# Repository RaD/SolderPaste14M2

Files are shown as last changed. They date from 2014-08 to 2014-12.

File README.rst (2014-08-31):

This is a clone of `Solder Paste Controller`__ project from Dead Bug Prototypes.

__ https://www.tindie.com/products/Dead_Bug_Prototypes/solder-paste-controller/

The main differences are:

- Usage ATtiny13 as a MCU.
- Firmware is written with assembler language.

Flashing:

    sudo \
    avrdude -p attiny13 \
            -c usbasp \
            -P usb
            -U lfuse:w:0x6A:m -U hfuse:w:0xFF:m
            -U flash:w:solderpaste.hex

Fuse online editor: http://www.engbedded.com/fusecalc/

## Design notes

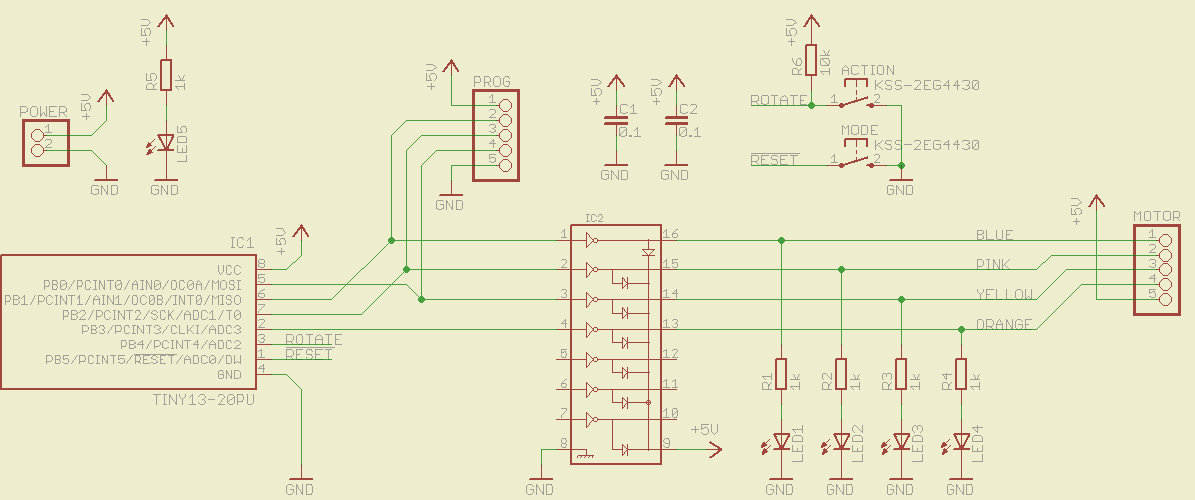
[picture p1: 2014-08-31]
pcb/schematic.png

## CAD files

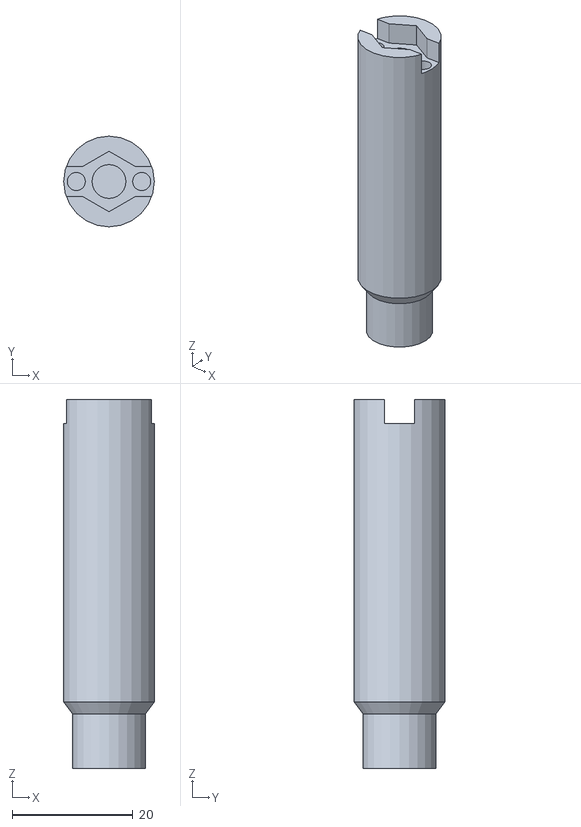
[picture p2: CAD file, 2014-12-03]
reprap/plunger.stl
15.0 x 15.0 x 61.0

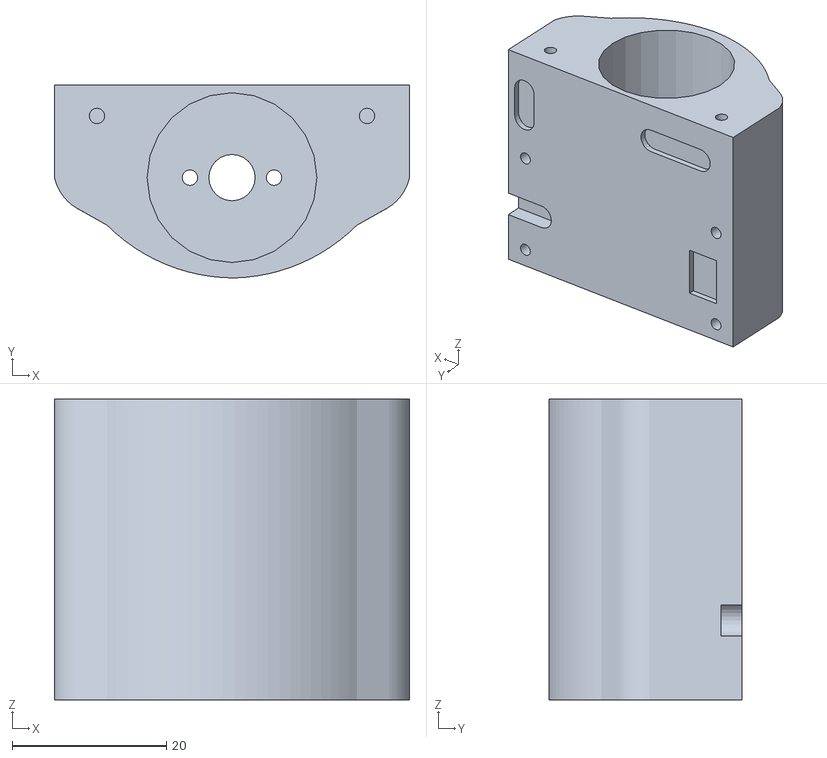
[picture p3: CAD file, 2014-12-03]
reprap/base.stl
46.0 x 25.0 x 39.0

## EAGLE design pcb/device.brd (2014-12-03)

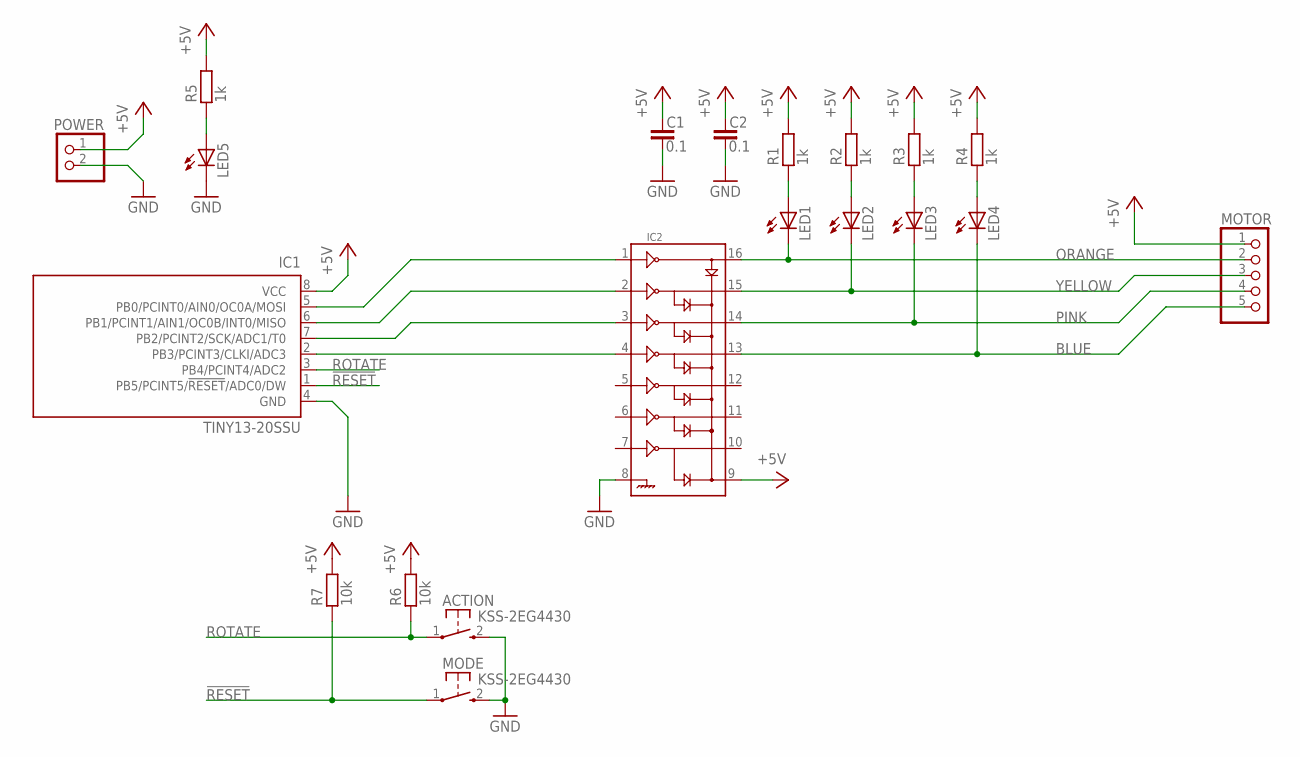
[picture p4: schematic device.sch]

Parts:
ACTION: KSS-2EG4430
C1, C2: 0.1; C0805
IC1: TINY13-20SSU; 8S1
IC2: ULN2003D; SO16
LED1, LED2, LED3, LED4, LED5: LEDCHIPLED_0805; CHIPLED_0805
MODE: KSS-2EG4430
MOTOR: PINHD-1X5_2.54; 1X05
POWER: PINHD-1X2_2.54; 1X02
R1, R2, R3, R4, R5: 1k; R0805
R6, R7: 10k; R0805

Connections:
!RESET: IC1.1 (PB5/PCINT5/!RESET!/ADC0/DW), MODE.1, R7.1
+5V: C1.1, C2.1, IC1.8 (VCC), IC2.9, MOTOR.1, POWER.1, R1.2, R2.2, R3.2, R4.2, R5.2, R6.2, R7.2
BLUE: IC2.13, LED4.C, MOTOR.5
GND: ACTION.2 (S), C1.2, C2.2, IC1.4 (GND), IC2.8, LED5.C, MODE.2 (S), POWER.2
unnamed: LED1.A, R1.1
unnamed: LED2.A, R2.1
unnamed: LED3.A, R3.1
unnamed: LED4.A, R4.1
unnamed: LED5.A, R5.1
unnamed: IC1.5 (PB0/PCINT0/AIN0/OC0A/MOSI), IC2.1
unnamed: IC1.6 (PB1/PCINT1/AIN1/OC0B/INT0/MISO), IC2.2
unnamed: IC1.7 (PB2/PCINT2/SCK/ADC1/T0), IC2.3
unnamed: IC1.2 (PB3/PCINT3/CLKI/ADC3), IC2.4
ORANGE: IC2.16, LED1.C, MOTOR.2
PINK: IC2.14, LED3.C, MOTOR.4
ROTATE: ACTION.1, IC1.3 (PB4/PCINT4/ADC2), R6.1
YELLOW: IC2.15, LED2.C, MOTOR.3

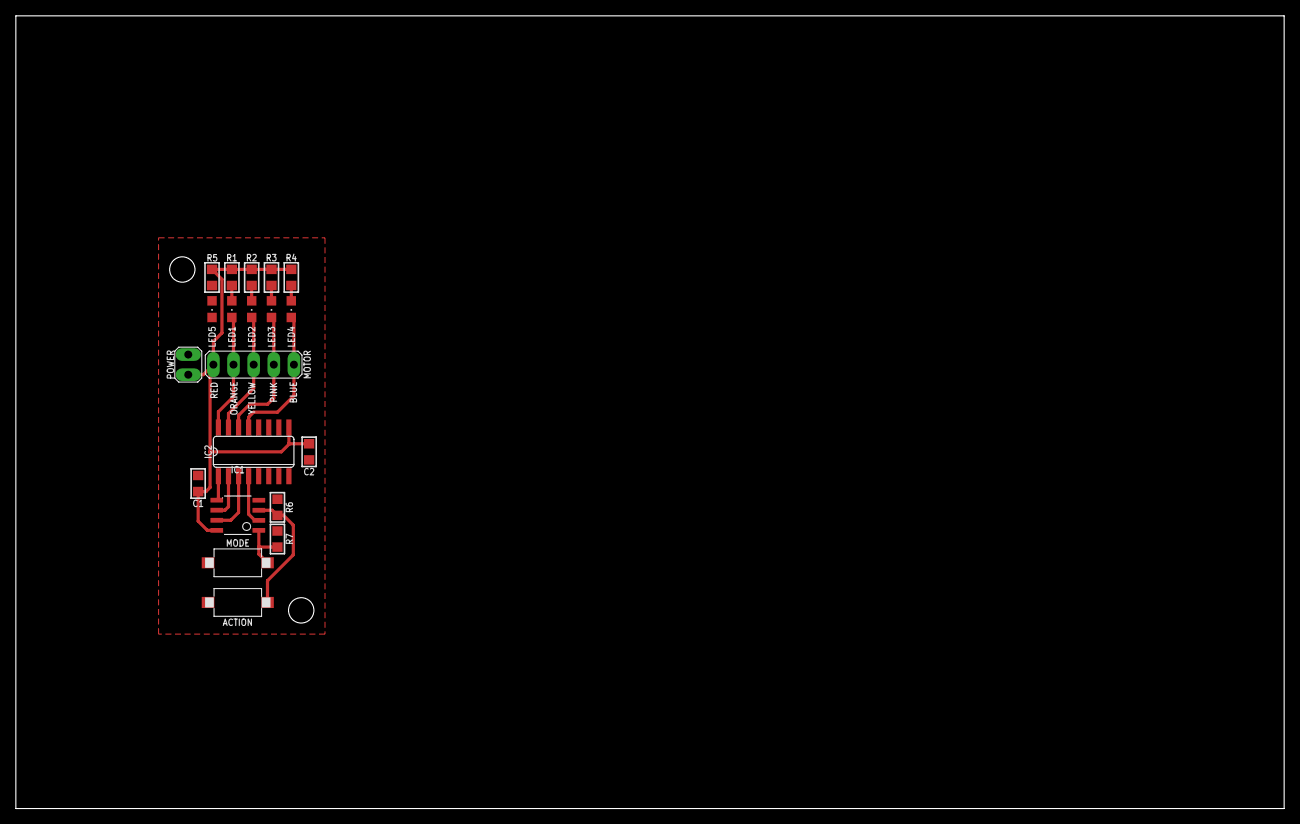
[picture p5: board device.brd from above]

Board: 2 copper layers, 160.0 x 100.0 mm, 20 parts (0 on the bottom side), 17 nets.

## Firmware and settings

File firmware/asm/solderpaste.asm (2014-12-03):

;
; This code is based on:
; * https://github.com/DeadBugPrototypes/SolderPaste14M2/
; * http://habrahabr.ru/post/110894/
;

; Internal RC oscillator at 9.6MHz; start-up time 14CK+64ms
; CKSEL=10, SUT=10

; Using this fuses chip works on 9.6MHz with HW divider by 8,
; so we get 1.2MHz, also we can program internal clock
; prescaler to divide this frequency by 128 (see CLKPR).
; Finally, MCU will work on 9375kHz.
; Be careful, while we use prescaler, so programmer hardware
; will work with chip only on 9.6MHz/128 = 75kHz.

.include "tn13def.inc"

; Port usage
; PB0-3 - output for stepper motor
; PB4   - control button
; PB5   - mode button


; Register defines:
.def    TMP     = R21
.def    SHIFT   = R16
.def    MASK    = R17
.def    STATE   = R18    ; status
.def    DELAY   = R19    ; delay counter
.def    CHANGE  = R20    ; used for EOR

.equ    MOTOR_BIT = 0    ; if set, motor is running
.equ    DIR_BIT   = 1    ; if set, rotating left
.equ    PAUSE     = 0xEA ; it is about 100ms for current prescaler
                         ; 9375kHz/10/4 (ticks per delay loop)

;;; Write to port macro.
.macro outm
        ldi     TMP, @1
        out     @0, TMP
.endm

;;; Rotate left macro
.macro rolm
        bst     @0, 7
        rol     @0
        bld     @0, 0
.endm

;;; Rotate right macro
.macro rorm
        bst     @0, 0
        ror     @0
        bld     @0, 7
.endm


.cseg
.org    0x0000

        rjmp    RESET
        rjmp    EXT_INT0      ; IRQ0 Handler
        rjmp    PC_INTO0      ; Pin Change Interrupt Handler
        rjmp    TIM0_OVF      ; Timer0 Overflow Handler
        rjmp    EE_RDY        ; EEPROM Ready Handler
        rjmp    ANA_COMP      ; Analog Comparator Handler
        rjmp    TIM0_COMPA    ; Timer0 CompareA Handler
        rjmp    TIM0_COMPB    ; Timer0 CompareB Handler
        rjmp    WDT_OVF       ; Watchdog Timer Overflow Handler
        rjmp    ADC_RDY       ; ADC Conversion Complete Interrupt Handler

; Unused vectors are simple return to program

.org    0x000A

;;; Pin Change Interrupt Handler
;;; It just changes the MOTOR_BIT in status register.
PC_INTO0:
        push    TMP

        sbr     STATE, (1<<MOTOR_BIT)   ; guess button is pressed
        sbic    PINB, 4                 ; check button state, if pressed
                                        ; skip the next command
        cbr     STATE, (1<<MOTOR_BIT)   ; button isn't pressed

        ; finish interrupt
        outm    GIFR, (1<<PCIF)

        pop     TMP

        ; dirty hack :)
EXT_INT0:
TIM0_OVF:
EE_RDY:
ANA_COMP:
TIM0_COMPA:
TIM0_COMPB:
WDT_OVF:
ADC_RDY:
        reti

; MCU initialization and main loop

RESET:
        ; check the reset type
        ;in      TMP, MCUSR
        ;outm    MCUSR, 0    ; clearing is mandatory
        ;ldi     CHANGE, (1<<DIR_BIT) ; change mask
        ;sbrs    TMP, EXTRF
        ;ldi     STATE, (1<<DIR_BIT) ; rotating
        ;eor     STATE, CHANGE

        ; stack init
        outm    SPL, low(RAMEND)

        ; slowdown the MCU
        outm    CLKPR, (1<<CLKPCE)  ; activate prescaler change
        outm    CLKPR, (1<<CLKPS2) | (1<<CLKPS1) | (1<<CLKPS0) ; /128


        ; set initial values
        ldi     SHIFT, 0b00110011   ; shift value
        ldi     MASK, 0b00001111    ; shift mask
        ldi     DELAY, PAUSE

        ; setup interrupt
        outm    GIMSK, (1<<PCIE)    ; enable Pin Change interrupt
        outm    PCMSK, (1<<PCINT4)  ; on PB4

        ; setup port
        outm    DDRB, (1<<DDB3)|(1<<DDB2)|(1<<DDB1)|(1<<DDB0)

        sbi     PORTB, PORTB4       ; enable pullup on PB4

        ; enable interrupt on any change and activate pullups
        outm    MCUCR, (1<<ISC00) | (1<<PUD)

        sei                         ; global interrupt enable

;;; Main Loop
;;;
        ldi     STATE, (1<<DIR_BIT)
MAIN:
        sbrc    STATE, MOTOR_BIT    ; skip if bit cleared
        rcall   ROTATION
        ;sleep
        rjmp    MAIN


;;; Function checks the direction and rotate motor by one
;;; step in particular direction.
ROTATION:
        sbrc    STATE, DIR_BIT      ; skip if bit cleared
        rjmp    MOVE_RIGHT

        rolm    SHIFT
        rjmp    ROTATE

MOVE_RIGHT:
        rorm    SHIFT

ROTATE:
        mov     TMP, SHIFT
        and     TMP, MASK
        out     PORTB, TMP
        rcall   DELAYING
        ret


;;; Delays execution
;;;
DELAYING:
        push    TMP
        mov     TMP, DELAY
DELAY_LOOP:
        dec     TMP
        nop
        brne    DELAY_LOOP
        pop     TMP
        ret


.exit

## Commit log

2014-08-28 A first glance on the PCB.
    [device.brd, device.sch]
2014-08-28 Add Pin Change interrupt and fix switch mode part.
    [solderpaste.asm]
2014-08-31 Motor datasheet.
2014-08-31 Schematic for fast viewers.
2014-08-31 Fix motor connection and add pullup on action pin.
    [device.brd, device.sch]
2014-08-31 Make motor rotating.
2014-12-01 Small change of RESET detection code.
    [solderpaste.asm]
2014-12-03 Almost ready PCB.
    [device.brd, device.sch]
2014-12-03 Original STL.
    [base.stl, plunger.stl]

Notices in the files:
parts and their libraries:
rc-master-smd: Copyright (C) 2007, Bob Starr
